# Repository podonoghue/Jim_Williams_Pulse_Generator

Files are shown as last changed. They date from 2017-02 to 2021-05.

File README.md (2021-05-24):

# Jim_Williams_Pulse_Generator
    
**Note:  The operation of this circuit depends on the breakdown characteristics of the 2N2369 transistor used.**

**Please refer to the Application notes provided.**  

I had no problems with the boards I constructed but I have had reports of the circuit not working.  The 2N2369 transistors appears to be no longer available. I have no experience with using the circuit with 2N2369A or BSX20 devices.  Ihave a report that is does not work with these devices likely due to insufficient voltage to breakdown.

This module produces a pulse with a very fast rise time.   
Its main use is for testing oscilloscope rise-time and hence estimating bandwidth.  
For convenience the module is powered from a micro-usb socket.  
Most current oscilloscopes have a USB host socket that can provide the power needed.   
Connection to the oscilloscope will require a BNC-to-BNC adapter.  
A length of 50ohm coax should be used to extend the pulse so that rise-time may be measured.  

References:  
<a href="http://cds.linear.com/docs/en/application-note/an72f.pdf">A Seven-Nanosecond Comparator for Single Supply Operation, Linear Technology’s Application Note 72, May 1998</img></a>  
<a href="http://cds.linear.com/docs/en/application-note/an47fa.pdf">High Speed Amplifier Techniques, Linear Technology’s Application Note 47, August 1991</img></a>  

This is an Altium designer project.  

Refer to the PDFs in the Project Outputs directory for layout and BOM
<a href="https://github.com/podonoghue/Jim_Williams_Pulse_Generator/blob/master/Hardware/Project Outputs for Pulser/Pulser.PDF">PDF Documentation</img></a>

# Top Image  
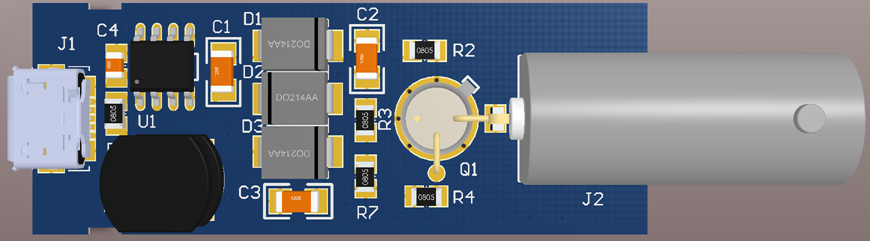
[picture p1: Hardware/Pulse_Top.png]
Top image Top Board Image
  
# Bottom image  
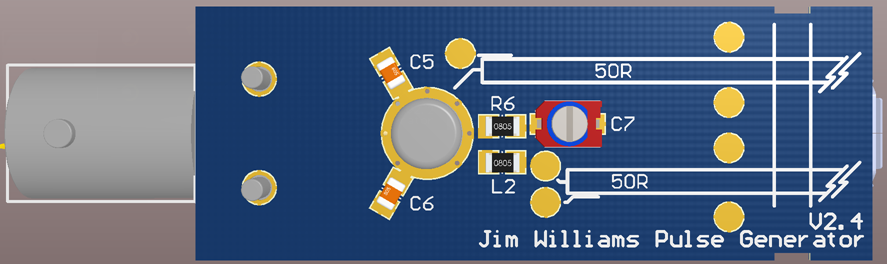
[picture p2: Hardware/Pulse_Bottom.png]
Bottom image Bottom Board Image
  
# 3D Image  
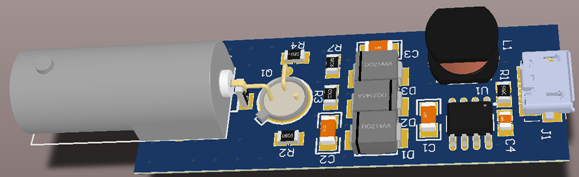
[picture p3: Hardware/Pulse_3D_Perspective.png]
3D image 3D Board Image
  
# Example waveforms from 500MHz DSO, 50R termination direct connection to BNC input
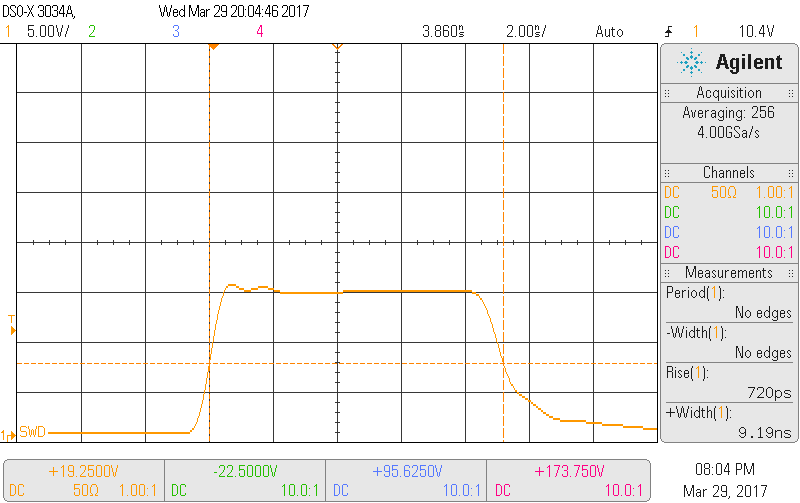
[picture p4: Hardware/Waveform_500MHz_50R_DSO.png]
Measured Waveform

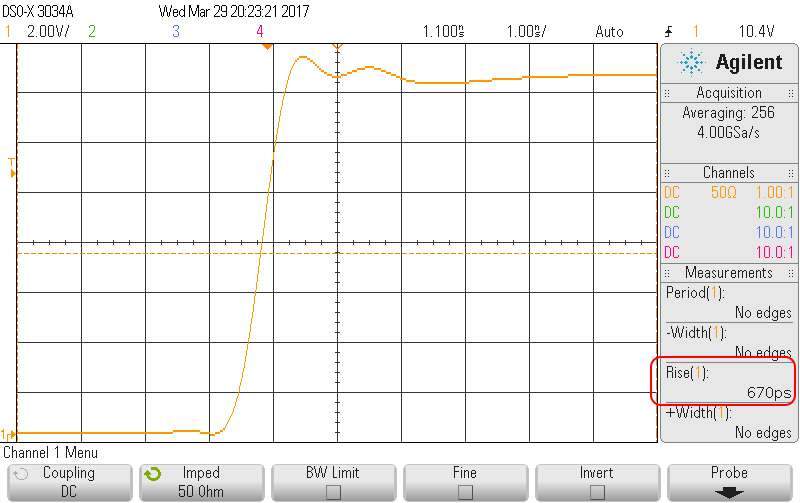
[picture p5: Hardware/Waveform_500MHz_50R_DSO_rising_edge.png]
Measured Waveform

# Example waveforms from 500MHz DSO, 500MHz probe with BNC converter
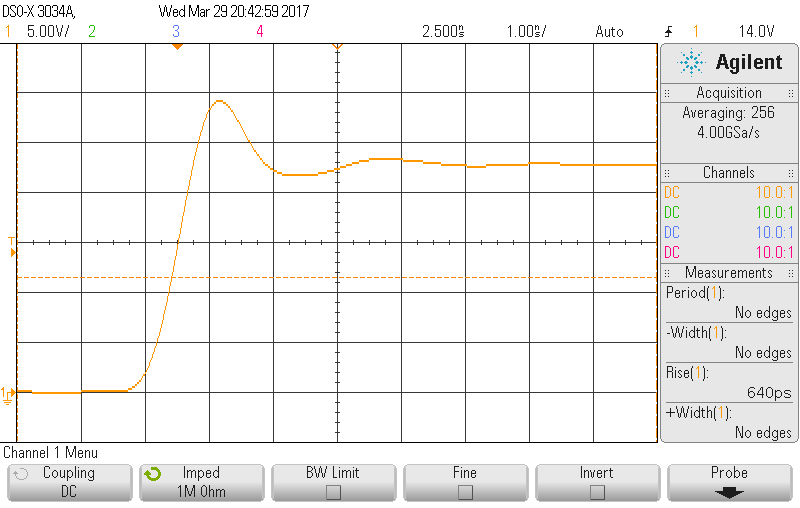
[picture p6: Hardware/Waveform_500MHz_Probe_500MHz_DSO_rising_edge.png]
Measured Waveform

  
PCBs may be ordered from OSH park

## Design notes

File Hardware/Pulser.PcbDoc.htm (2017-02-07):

Reporting Options

# File in Previous Format

Date | : | 17/10/2016
Time | : | 6:07:20 PM
Filename | : | C:\Users\podonoghue\Documents\Development\PCB\Pulser\Pulser.PcbDoc

Version | Warning

This file was generated by an earlier version of the software

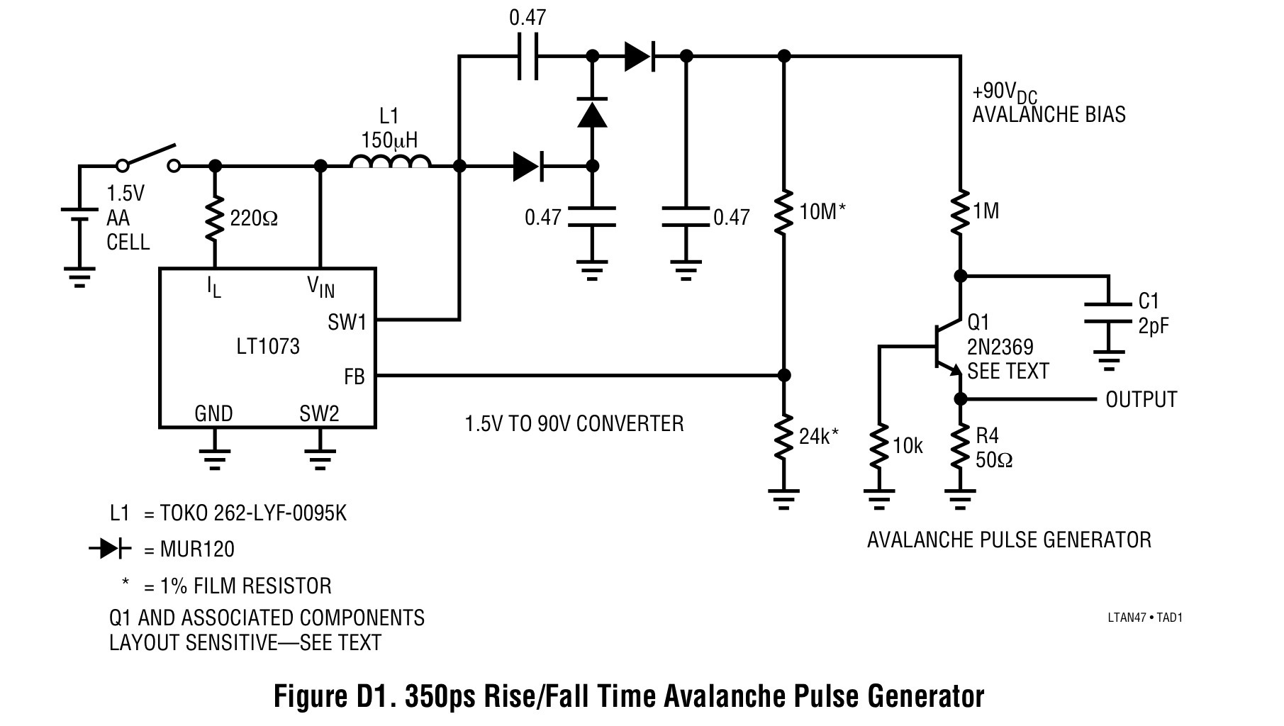
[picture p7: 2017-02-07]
Hardware/Pulser.jpg

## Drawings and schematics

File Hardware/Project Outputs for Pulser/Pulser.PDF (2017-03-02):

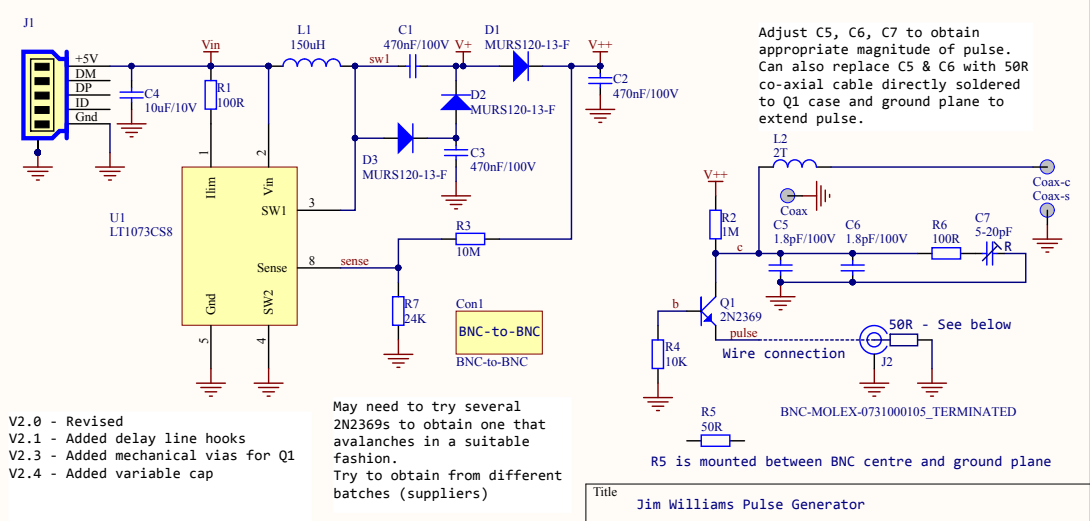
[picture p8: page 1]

Adjust C5, C6, C7 to obtain
appropriate magnitude of pulse.
Can also replace C5 & C6 with 50R
co-axial cable directly soldered
to Q1 case and ground plane to
extend pulse.

May need to try several
2N2369s to obtain one that
avalanches in a suitable
fashion.
Try to obtain from different
batches (suppliers)

V2.0 - Revised
V2.1 - Added delay line hooks
V2.3 - Added mechanical vias for Q1
V2.4 - Added variable cap

R5 is mounted between BNC centre and ground plane

Title
Jim Williams Pulse Generator

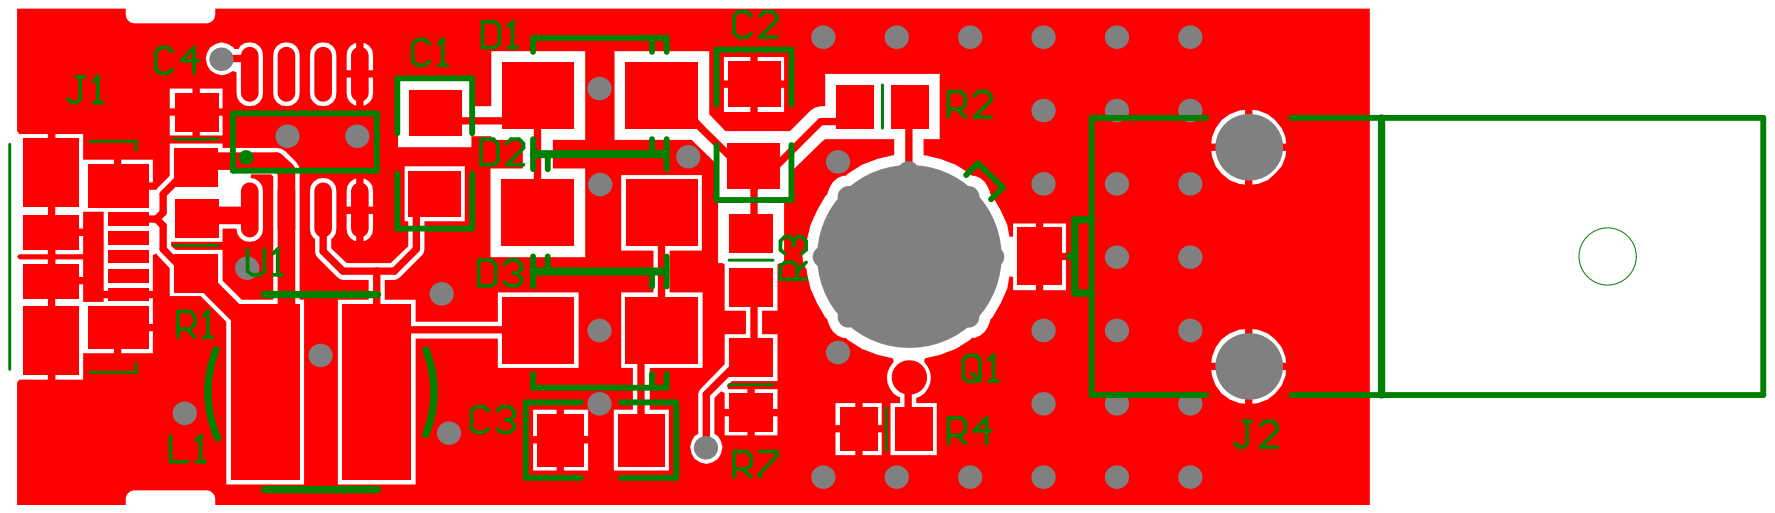
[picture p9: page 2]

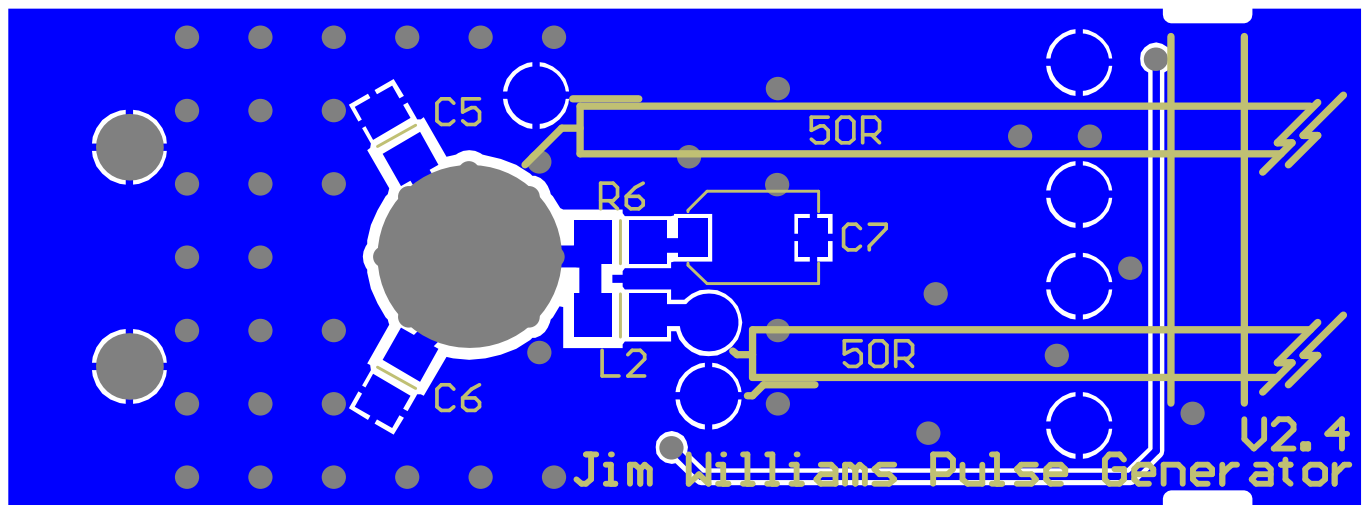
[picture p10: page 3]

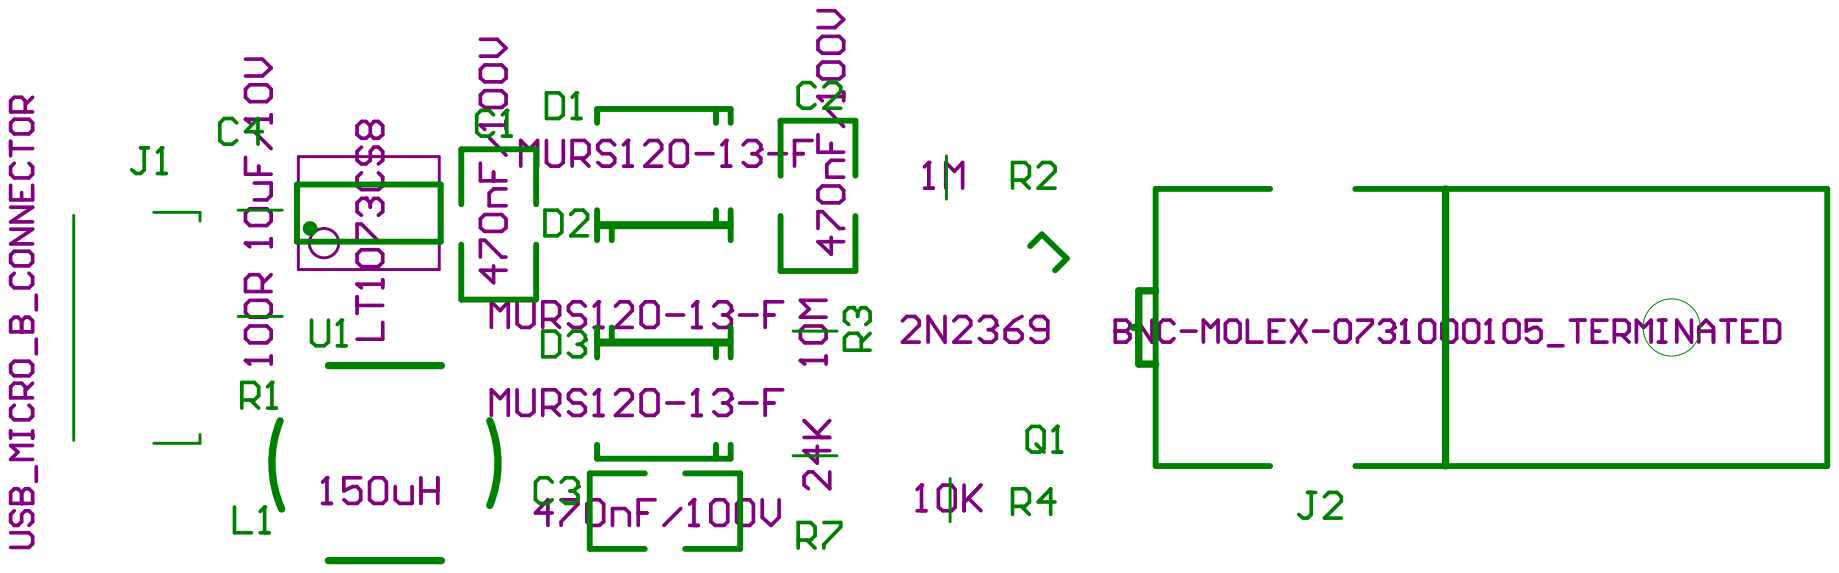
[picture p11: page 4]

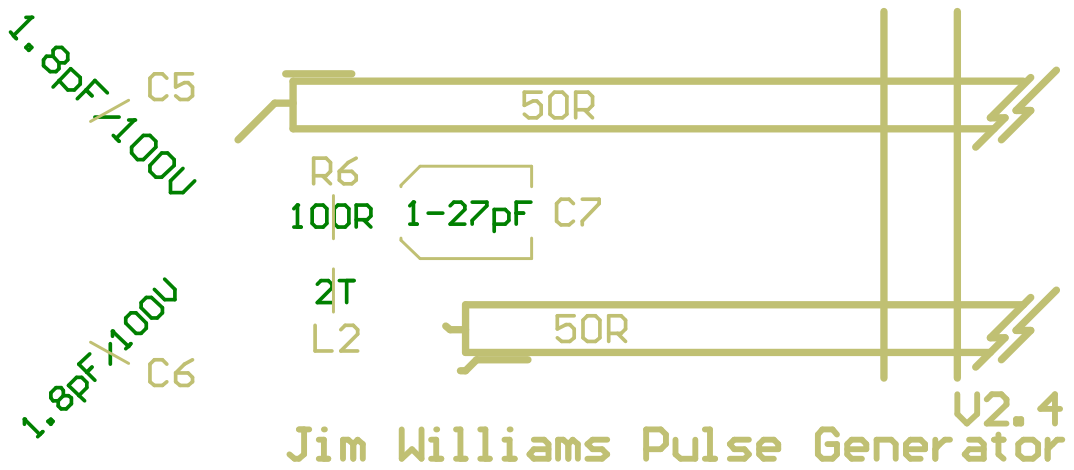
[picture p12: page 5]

Bill of Materials | Bill of Materials For Project [Pulser.PrjPCB] (No PCB Document Selected)
Source Data From: | Pulser.PrjPCB
Project: | Pulser.PrjPCB
Variant: | None
Creation Date: | 2/03/2017 | 10:52:52 PM
Print Date: | 02-Mar-17 | 10:52:57 PM
Footprint | Comment | Farnell PN | Digikey | Designator | Description | Quantity
CCNP3216-1206 | 470nF/100V | 2497173 | | C1, C2, C3 | Capacitor | 3
CCNP2012-0805 | 10uF/10V | | | C4 | Capacitor SMT 0805 | 1
CCNP2012-0805 | 1.8pF/100V | 2672812 | | C5, C6 | Capacitor | 2
CAP_TRIM_SMT_TZC3 | 5-20pF | 9528652 | | C7 | Trimmer Capacitor muRata TZC3 series | 1
BNC-to-BNC | BNC-to-BNC | 4195255 | | Con1 | | 1
SMB_Diode | MURS120-13-F | 1858618 | | D1, D2, D3 | Fast / Ultrafast Diode, 200 V, 1 A | 3
MOLEX - 47346-0001 | USB_MICRO_B_CONNECTOR | 1568026 | | J1 | USB Micro-B Connector | 1
BNC_RA CON - Molex - Resistor | BNC-MOLEX-0731000105_TERMINATED | 1418237 | WM5524-ND | J2 | BNC Connector | 1
INDUCTOR_SMT | 150uH | 1864148 | | L1 | Inductor - SMT 3mm | 1
CL2012-0805 | 2T | | | L2 | Resistor | 1
TO-18-flush | 2N2369 | 9206850 | | Q1 | High Speed Switching Transistor | 1
CR2012-0805 | 100R | | | R1, R6 | Resistor | 2
CR2012-0805 | 1M | | | R2 | Resistor | 1
CR2012-0805 | 10M | | | R3 | Resistor | 1
CR2012-0805 | 10K | | | R4 | Resistor | 1
CR3216-1206 | 50R | | | R5 | Resistor | 1
CR2012-0805 | 24K | | | R7 | Resistor | 1
SO-8_L | LT1073CS8 | 1273663 | | U1 | Micropower DC/DC Converter (Adjustable, 212mV reference) | 1
| | | | | | 24
Approved | | Notes

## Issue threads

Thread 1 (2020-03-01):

Question as to L2 resistor value

djadeski, 2020-03-01:
The PCB schematic doesn't call out the R value of L2 resistor - is that found by experimentation or did you find a specific value that works well?

podonoghue, 2020-03-01:
Hi,
This was just for experimentation.  I tried 2Turns of wire as a small inductor but it had little effect.
Just connect the coax directly using the other location.

bye

Closed 2021-05-24.

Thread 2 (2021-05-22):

Sadly none of 2N2369A work in these pcb boards. There is no oscillation!

Alectronics, 2021-05-22:
There must be something very wrong with these OSH Park pcb boards of Jim Williams Fast Rise Pulse Generator. I've tested my brandnew 2N2369A in part of Kerry Wong's transistor circuit with the external 120V input with 220Kohm resistor in the collector of my transistor under test. It worked splendidly at around 119V input giving about 40V on the avalanching collector of the transistor under test. And my Tektronix oscilloscope showed a frequency that depended on the recovery time of the transistor,  and also showed a fine Avalanche pulse when was 'zoomed' in on the pulse.
But the same new transistors (10 brandnew ones from Digikey!) never worked in the OSH Park boards I received! I used exactly the listed components from version March 2017 also v2.4, but only the LT1073 works giving about 89V DC on the collector serieresistance of the 2n2369A.
So I am almost sure that these sold boards have some kind of HF failure or any other design flaw! Because the transistors when used in the OSH Park boards never work as intended and it was all a very expensive and useless project! And I hate to say this but someone is selling crap and boards that are just not working!

podonoghue, 2021-05-22:
Hi Alectronics,
I'm sorry to hear of your problems.
I don't really have any insight into the results you are getting.
I only built 1 board using a PCB from OSH Park and it worked fine.
A further 10 were built for a lab class but used PCBs from JLCPCB - they also worked,
Leakage on the PCB could be a problem but I would really think it unlikely to be a issue.
I don't know if soldering residue (cooked flux) could be an issue.
The circuit relies on the breakdown of the transistor which is **not** well defined and it may be necessary to select transistors.  I bought from a couple of suppliers in case there was a variation in the breakdown threshold but found all I tied worked (11).
I'm not sure where the one from OSH park is now and I don't have access to the 10 at work so I can't check the voltages on them.  I'll hunt around and see if I can find the OSH park one for voltage measurement.
Good luck.

Alectronics, 2021-05-23:
Thanks podonoghue for the fast reply. I also tried if the transistor would oscillate if I provided the collectorvoltage externally but it still failed to work. So the design is flawed since I can't find any issue on the board after rechecking, Also I tried to adjust the 1.8pF caps by doubling those as also the 10uF on the 5V input but without any success. Still I wonder if I should change Ilim from 100 ohm to a 220 ohm resistor like is given in all other LT1073 operated pulser circuits, including in the LT1073 datasheet.

podonoghue, 2021-05-23:
Hi,
I'm sorry I didn't read you original posting very well.
I don't have the circuit to check voltages but it is not designed to produce such a high voltage - obviously since the caps (C2) are specified as 100V.  The 2N2369 would be expected to break down at less than this since its Vcbo is only 40V.

I think it is likely the transistors that you are using have a better breakdown voltage than expected.
It is not uncommon for manufacturers to 'improve' transistors - actually fold together lines by using later generation devices with better but compatible specs.
I would suggest trying transistors from a different supplier but there are no guarantees.

bye

Alectronics, 2021-05-23:
Okay understood!
I was afraid that you where going to say something like that.
I bought my 2N2369A from digikey and a second order with other parts is underway. Also some BSX20 types. But since they do work perfectly in Kerry Wong's DIY Pulse Giver the design of your from OSH Park bought boards is flawed!
The CE voltage should be much higher to always work!
I know because if the starting voltage is much higher they function fine as intended! Tested with my DY294 as DC voltage provider and Kerry Wong's transistor circuit.
And some kind of warning about this would have been appreciated! Because now I spend over 140 USdollar on making 2 boards that simply never work!

Albert.
________________________________
Van: podonoghue ***@***.***>
Verzonden: zondag 23 mei 2021 12:43
Aan: podonoghue/Jim_Williams_Pulse_Generator ***@***.***>
CC: Alectronics ***@***.***>; Author ***@***.***>
Onderwerp: Re: [podonoghue/Jim_Williams_Pulse_Generator] Sadly none of 2N2369A work in these pcb boards. There is no oscillation! (#2)

Hi,
I'm sorry I didn't read you original posting very well.
I don't have the circuit to check voltages but it is not designed to produce such a high voltage - obviously since the caps (C2) are specified as 100V. The 2N2369 would be expected to break down at less than this since its Vcbo is only 40V.

I think it is likely the transistors that you are using have a better breakdown voltage than expected.
It is not uncommon for manufacturers to 'improve' transistors - actually fold together lines by using later generation devices with better but compatible specs.
I would suggest trying transistors from a different supplier but there are no guarantees.

bye

—
You are receiving this because you authored the thread.
Reply to this email directly, view it on GitHub<https://github.com/podonoghue/Jim_Williams_Pulse_Generator/issues/2#issuecomment-846541736>, or unsubscribe<https://github.com/notifications/unsubscribe-auth/AUFU6ZAP53M5TP6GLVZMKG3TPDL37ANCNFSM45KUJEYQ>.

podonoghue, 2021-05-24:
Hi,
I have linked to the two Application notes on the main Github page that describe this circuit and discuss transistor selection but I should draw more attention to the consideration of the transistors.  I have now done this.

As a data point all 11 boards that we built worked.  The transistors used were purchased on two occasions several years apart so I did not think it that critical of transistor devices.  For the prototypes I built, the devices were purchased from Element-14 in Australia and are 2N2369 not **2N2369A**.  They are now marked as unavailable and obsolete on E-14. I cannot check the boards that where built were I formerly worked that were done more recently.  The transistor availability situation is similar on Digikey with 2N2369 as non-stocked.  It looks like they are generally unavailable.
The use of 2N2369A may account for the differing results.  Yes they have the same breakdown spec. but this is a minimum value and may have improved on the A version due to process changes.
I have not had anyone else report difficulties but I have no idea whether others have been built nor how recently.

The differing results for the actual boards is incomprehensible.  The PCB design is not particularly critical to work.  It simply minimises the capacitance at the emitter to ensure the fastest rise times.  Even if capacitance is excessive, or the layout changed, it should at least oscillate if you apply an external voltage sufficient to cause breakdown as you have done.

bye

Alectronics, 2021-05-24:
Thank you very much podonoghue for that clear explanation!

That must be the reason since both my boards are indeed made with 2N2369A types that apparently completely fail to oscillate in the fast kHz range!
And these were apparently produced in India at that time according to the Digikey sheet. That also mentioned that they were PBfree.
Good that you added this fact to the design publication.
Maybe they left out the gold substance in the manufacturing process of the transistor in the newer types? Like the gold they used in those Russian tunneldiodes that also qualify to work in use as fast avalanche pulser?

I do hope that these Jim Williams boards will still become useful when the right transistor somewhere becomes available? Maybe my ordered BSX20 will work?
Anyway thanks for your fast and clear reply!
All the Best!

________________________________
Van: podonoghue ***@***.***>
Verzonden: maandag 24 mei 2021 05:26
Aan: podonoghue/Jim_Williams_Pulse_Generator ***@***.***>
CC: Alectronics ***@***.***>; Author ***@***.***>
Onderwerp: Re: [podonoghue/Jim_Williams_Pulse_Generator] Sadly none of 2N2369A work in these pcb boards. There is no oscillation! (#2)

Hi,
I have linked to the two Application notes on the main Github page that describe this circuit and discuss transistor selection but I should draw more attention to the consideration of the transistors. I have now done this.

As a data point all 11 boards that we built worked. The transistors used were purchased on two occasions several years apart so I did not think it that critical of transistor devices. For the prototypes I built, the devices were purchased from Element-14 in Australia and are 2N2369 not 2N2369A. They are now marked as unavailable and obsolete on E-14. I cannot check the boards that where built were I formerly worked that were done more recently. The transistor availability situation is similar on Digikey with 2N2369 as non-stocked. It looks like they are generally unavailable.
The use of 2N2369A may account for the differing results. Yes they have the same breakdown spec. but this is a minimum value and may have improved on the A version due to process changes.
I have not had anyone else report difficulties but I have no idea whether others have been built nor how recently.
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
podonoghue, 2021-05-27:
Hi,
You should be able to add images by drag and drop on Github.
I'll try below:
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

Alectronics, 2021-05-27:
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
Above photo's show the Kerry Wong board I made to test the present 2N2369A types with successfully. Next photos show the bad and strange OSH Park curves after I 'upgraded' the Uce voltage to about 136V DC.
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

Alectronics, 2021-05-27:
Above scopesignals of Kerry's and the Osh Park board were both made with the exact same DC voltage of well over 90V. (136V DC!). And Kerry's circuit doesn't work either on <90V DC because it needs at least about 122.5V DC on the 220 kohm input resistor to the collector of the 2N2369A!

Alectronics, 2021-05-27:
PS: Maybe the results are better when the high voltage 1206 0.47uF 250V capacitors and the 1206 3.9Mohm resistors that were also ordered are finally here to replace the present 100V caps and add a 3.9Mohm serial resistorvalue to the present 10Mohm resistor to FB of the LT1073. But I'm afraid that the OSH Park board still won't work as expected because even when an excellent ripple-free DC signal is externally fed to the collector via a 220 kohm resistor the signal is still strange and distorted. And when I feed the OSH Park board from its microUSB connection it gives the same but very weak signal that is very hard to trigger on and way too unsteady to show on the scopescreen. Next photo shows the externally fed OSH Park board and the resulted strange scopesignal.
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
And next photo shows the almost perfect signal of the previously shown Kerry Wong transistor board when fed by the same DC voltage. (with a little ringing in the falling edge).
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
The signal output of Kerry Wong's transistor weakend by starting to dim on the scopescreen when the voltage dropped to about 58V DC but still kept its same shape. Below it it vanished completely. But the OSH Park board sadly was not triggerable even when fed by its own LT1073 generated 90V DC voltage. I am not sure if it are the China LT1073 chips that have something to do with this because one of the five recived was already completely defect, and a second one only produced 50V max output. And chips 3 and 4 were fine each producing 89V DC. Chip 5 wasn't tested.

Alectronics, 2021-06-08:
Update: only AFTER the collector resistor was reduced from 1Mohm to 220Kohm and the C2 0,47nF cap was replaced by a 250V max capacitor, (C1 and C3 are still below 63V DC so 100V max still okay!) plus 10Mohm R3 was increased to 13,9 Mohm (by adding a 3,9Mohm in serie) the voltage became high enough to make avalanche oscillate the present 2N2369A transistors working on the 125V generated voltage by chip LT1073!

Closed 2021-05-27.

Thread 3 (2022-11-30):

A question about assembly of PCB ...

softfoot, 2022-11-30:
Looking at the pictures of an assembled board you have cut the collector lead off so I assume you rely on contact betweek the can of the transistor and the copper pad that surrounds it ??

Does it need to be soldered or is a push fit enough (my transistors are a little loose) ??
Would a bit of soft copper wire to make it a tight push fit be OK ??

Regards,
Dave

podonoghue, 2022-11-30:
I soldered the can of the transistor which I confirmed was connected to the appropriate pin.
This may not be a desired technique but I had no problem.
Please note the feedback on the variable results due to variations in the transistors.
Also note that I used it with a digital scope so low repetition rate wasn't an issue.

softfoot, 2022-12-01:
Thanks for that very prompt response.
I managed to find some 2n2369's (NOT "A's") on ebay from a couple of sources and tested them on a "lash up" and found that they all worked at <80V and were consistent in their operation on my TDS744A.
I'll start soldering when I find my reading glasses (Even then 0805's are a bit of a struggle. At least you didn't use 0402's which dissapear in the slightest draft ) :-)
Regards,
Dave

Closed 2022-12-24.

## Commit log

2017-02-07 V1.0 Initial commit
    [Pulser.GBL, Pulser.GBO, Pulser.GBP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]
2017-02-07 V2.0 Initial commit
    [Pulser.PcbDoc, Pulser.PrjPCB, Pulser.SchDoc]
2017-02-08 V2.0 Made L pads larger (easier soldering)
    [Pulser.PcbDoc, Pulser.SchDoc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]
2017-02-08 V2.1 Added coax option
    [Pulser.GBL, Pulser.GBO, Pulser.GBP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]
2017-02-09 V2.2 Added coax overlay
    [Pulser.PcbDoc, Pulser.PrjPCB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]
2017-02-15 V2.3 Added mechanical vias
    [Pulser.GBL, Pulser.GBO, Pulser.GBP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]
2017-02-19 V2.4 Added Trimmer + series resistor
    [Pulser.GBL, Pulser.GBO, Pulser.GBP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]
2017-03-02 V2.4 Updated PDF (values etc)
    [Pulser.PcbDoc, Pulser.SchDoc]
2017-03-10 V2.4 Production
    [Pulser.PcbDoc]
